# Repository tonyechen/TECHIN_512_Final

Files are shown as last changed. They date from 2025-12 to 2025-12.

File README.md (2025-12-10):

# Don't Let Scrappy Die! 🤖

A 90s-style handheld electronic game where you control a rebellious robot car named Scrappy who's determined to drive off the table. Your mission: keep Scrappy alive by countering his chaotic movements before time runs out!

## 🎮 How to Play

### Setup
1. Place Scrappy on the flat operating platform (3D printed table)
2. Turn on both the **Controller** and **Scrappy** (the robot car)
3. Wait for the NeoPixel on the controller to turn **green**
4. The OLED screen will display the connection status
5. Once connected, the main menu appears - Bluetooth connection established!

### Game Start
1. Use the **rotary encoder** to select difficulty (Easy, Medium, Hard)
2. Press the **right button** to begin the game
3. Keep Scrappy from driving off the table!

### Controls

| Button | Action | Description |
|---|---|---|
| **UP** | Forward | Prompt Scrappy to move forward |
| **DOWN** | Backward | Prompt Scrappy to move backward |
| **LEFT** | Turn Left | Prompt Scrappy to turn left |
| **RIGHT** | Turn Right | Prompt Scrappy to turn right |
| **SHAKE** (Accelerometer) | Manual Mode | Take full control for 5 seconds |

### Movement
- Scrappy will briefly in direction entered

### Manual Mode (Shake to Activate)
- **Duration:** 5 seconds of full control
- **Warning:** Scrappy will NOT automatically stop during manual mode
- **Strategy:** Use wisely! Once you input a command, Scrappy follows it continuously until you send a new command

### Game Progression
- **10 Levels Total**
- **Level 1:** 10 seconds
- **Each Additional Level:** +2 seconds (Level 10 = 28 seconds)
- Successfully keep Scrappy alive for the time limit to advance

### Difficulty Settings

| Difficulty | Behavior |
|---|---|
| **EASY** | Slow, predictable movements |
| **MEDIUM** | Moderate speed, unpredictable |
| **HARD** | Fast, chaotic, sudden changes |

Higher difficulty = more irrational behavior and sudden movements!

### Win/Lose Conditions
- **GAME OVER:** Scrappy drives off the table (detected by ADXL345 accelerometer)
- **WIN:** Complete all 10 levels without Scrappy falling
- Shake the controller to restart after Game Over (no power cycling needed!)

---

## 🔧 Components Used

### Controller (Handheld Device)
- **XIAO ESP32C3** - Main microcontroller with Bluetooth
- **SSD1306 OLED (128x64)** - Display for menus, levels, and status
- **Rotary Encoder** - Difficulty selection and menu navigation
- **ADXL345 Accelerometer** - Shake detection for manual mode activation
- **4x Tactile Buttons** - Directional controls (UP, DOWN, LEFT, RIGHT)
- **NeoPixel LEDs** - Status indicators (connection, game state, battery)
- **3.7V LiPo Battery** - Portable power supply
- **On/Off Switch** - Power control

### Scrappy (Robot Car)
- **Adafruit QT Py ESP32-S3** - Robot microcontroller with Bluetooth
- **L298N Motor Driver** - Dual H-bridge for motor control
- **2x DC Motors** - Drive system for movement
- **ADXL345 Accelerometer** - Impact/fall detection (death sensor)
- **9V Alkaline Battery** - Robot power supply
- **On/Off Switch** - Robot power control

## 💾 Software Requirements

### CircuitPython Version
- **CircuitPython 10+** (Both controller and Scrappy)

### Controller Libraries
```
lib/
├── adafruit_displayio_ssd1306    # OLED display driver
├── adafruit_display_text         # OLED display text
├── adafruit_ble/                 # Bluetooth Low Energy
├── adafruit_adxl34x.mpy          # ADXL345 accelerometer
├── adafruit_bus_device/          # I2C/SPI support
├── neopixel.mpy                  # NeoPixel LED control
└── rainbow.mpy
```

### Scrappy Libraries
```
lib/
├── adafruit_ble/                 # Bluetooth Low Energy
├── adafruit_adxl34x.mpy          # ADXL345 accelerometer
└── adafruit_bus_device/          # I2C support
```

## 🎯 Implementation Details

### Bluetooth Communication (BLE UART)
- **Protocol:** Nordic UART Service over Bluetooth Low Energy
- **Range:** ~10 meters
- **Messages:**
  - `LEVEL:X:DIFFICULTY` - Start game at level X with difficulty
  - `UP`, `DOWN`, `LEFT`, `RIGHT` - Movement commands
  - `MANUAL` - Activate 5-second manual mode
  - `STOP` - Stop Scrappy between levels and  after Game Over
- **Responses:**
  - `CONNECTED` - Initial connection established
  - `ACK` - Command received successfully
  - `DEAD` - Scrappy has fallen (Game Over)

### Accelerometer Calibration & Filtering
#### Controller (Shake Detection)
- **Calibration:** Zero-offset calibration on startup (50 samples)
- **Filtering:** z axis magnitude detection
- **Threshold:** Configurable shake sensitivity
- **Purpose:** Detect shake gesture for manual mode

#### Scrappy Robot (Fall Detection)
- **Calibration:** Zero-offset calibration on startup
- **Detection Method:** Z-axis monitoring for sudden drops
- **Threshold:** Adjustable threshold for fall detection sensitivity
- **Purpose:** Detect when Scrappy falls off the table

### Movement System
- **Random Behavior:** Algorithm generates random directions, speeds, and durations
- **Speed Ranges:**
  - Easy: 55-60% motor power
  - Medium: 60-65% motor power
  - Hard: 65-70% motor power
- **Counter-Steering:** Override Scrappy Auto Movements

### NeoPixel Indicators
| Color | Status |
|---|---|
| **Red** | Not connected |
| **Green** | Connected to Scrappy |

### Display States
1. **Splash Screen** - Game title and version
2. **Connection Screen** - Shows "BLE Client" status
3. **Main Menu** - Difficulty selection
4. **Level Screen** - Shows current level, difficulty, last command sent, and response status from Scrappy
5. **Game Over Screen** - "Scrappy Died!" with restart option
6. **Victory Screen** - "You Win!" with celebration and restart option

---

## 📦 Enclosure Design

### Controller Enclosure
**Design Philosophy:** Sci-fi inspired components with functional layout

**Layout:**
- **Top Surface:** OLED screen and control buttons
- **Side Mounted:** Rotary encoder for easy thumb access
- **Bottom Front:** On/Off switch
- **Bottom Access:** USB-C charging port slot

### Scrappy Robot Enclosure
**Design Philosophy:** Inspired by Perry the Platypus. Hat serves as the opening for the enclosure

**Layout:**
- **Bottom Back:** On/Off switch
- **Side Mounted**: Wheels for controlling movement
---

## 📁 Repository Structure

```
├── src/
│   ├── controller/
│   │   ├── code.py                 # Main controller program
│   │   ├── display.py              # OLED display management
│   │   ├── controls.py             # Button and rotary encoder handling
│   │   ├── accelerometer.py        # Shake detection
│   │   └── README.md               # Hardware and Software requirement
│   └── scrappy/
│       ├── code.py                 # Main robot program
│       ├── motor.py                # L298N motor control
│       ├── movement_patterns.py    # Random movement logic
│       ├── accelerometer.py        # Fall detection
│       └── README.md               # Hardware and Software requirement
├── Documentation/
│   ├── system_diagram.png          # Overall system architecture
│   ├── Scrappy.kicad_sch           # Circuit Diagram for Scrappy
│   └── Controller.kicad_sch        # Circuit Diagram for Controller
└── README.md                       # This file
```

---

## 🚀 Getting Started

### Software Installation
1. Install CircuitPython 10.0+ on both ESP32 boards
2. Copy all files from `src/controller/` to the controller's CIRCUITPY drive
3. Copy all files from `src/scrappy/` to Scrappy's CIRCUITPY drive
4. Ensure all required libraries are present in `lib/` for each microcontroller

### Hardware Assembly
1. Follow circuit diagrams in `Documentation/` folder
2. Connect components according to pin configuration above
3. Secure batteries with proper polarity
4. Test all connections before enclosing
5. Install firmware and test functionality
6. Assemble into enclosures

---

## 🎓 Educational Value

This project demonstrates:
- **Wireless Communication:** BLE UART protocol implementation
- **Sensor Fusion:** Accelerometer calibration and filtering
- **State Machine Design:** Game states and transitions
- **Real-Time Control:** Motor PWM control and response timing
- **User Interface:** OLED graphics and menu systems
- **Embedded Systems:** Power management, resource constraints
- **Mechanical Design:** Enclosure design and assembly
- **Version Control:** Git/GitHub workflow

---

## 🏆 Credits

**Project Type:** Final Project for Embedded Systems Course  
**Inspired By:** 90s handheld games (Bop It, Brain Warp)  
**Platform:** CircuitPython on ESP32  
**License:** MIT

**Special Thanks:**
- TECHIN 512 Teaching team for guidance and component provision
- Maker Space for tools and materials
- Adafruit for excellent CircuitPython libraries

---

## 📝 License

MIT License - Feel free to modify and share!

---

**Remember:** Scrappy wants to die. Don't let him. Good luck! 🎮🤖

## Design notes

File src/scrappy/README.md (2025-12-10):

## Library Needed:
- adafruit_ble
- adafruit_adxl34x.mpy
- adafruit_bus_device

## Hardward requirement:
- 1 QT Py ESP32-S3
- 1 Switch
- 1 9V Alkaline battery
- 1 Accelerometer (ADXL 345)
- 2 DC Motors
- 1 L298N Motor Driver

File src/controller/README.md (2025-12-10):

Library Needed:
- adafruit_ble
- adafruit_bus_device
- adafruit_display_text
- adafruit_adxl34x.mpy
- adafruit_displayio_ssd1306
- neopixel.mpy
- rainbow.mpy

Hardward requirement:
- 1 Xiao ESP32C3
- 1 Neopixel
- 1 SSD1306 OLED screen
- 4 Push Buttons
- 1 rotary encoder
- 1 switch
- 1 3.7V LiPo Battery
- 1 Accelerometer (ADXL 345)

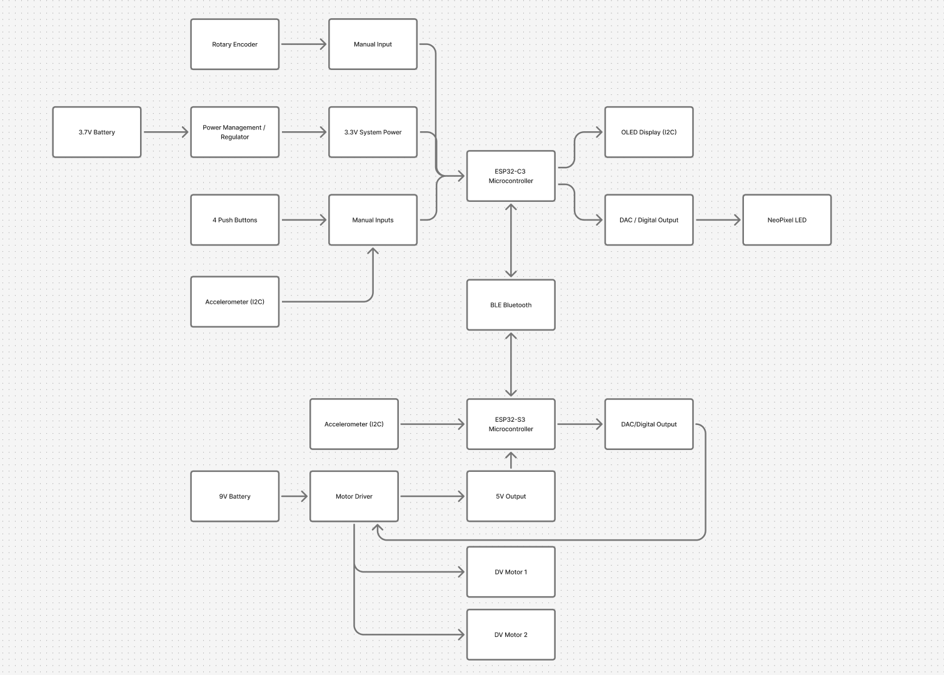
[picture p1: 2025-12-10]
Documentation/system_diagram.png

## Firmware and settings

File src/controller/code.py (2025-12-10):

import board
import time
import busio
import displayio
import i2cdisplaybus
import adafruit_displayio_ssd1306
from adafruit_ble import BLERadio
from adafruit_ble.advertising.standard import ProvideServicesAdvertisement
from adafruit_ble.services.nordic import UARTService
from buttons import Buttons
from accelerometer import Accelerometer
from display import DisplayManager
from rotary_encoder import RotaryEncoder
from neopixel_status import NeoPixelStatus

# Release any existing displays
displayio.release_displays()

# Setup I2C for OLED
i2c = busio.I2C(board.SCL, board.SDA)
display_bus = i2cdisplaybus.I2CDisplayBus(i2c, device_address=0x3C)
display = adafruit_displayio_ssd1306.SSD1306(display_bus, width=128, height=64)

# Initialize display manager
display_mgr = DisplayManager(display)

# Initialize accelerometer
accelerometer = Accelerometer(i2c=i2c, shake_threshold=15.0, cooldown_time=0.5)
print("Calibrating accelerometer...")
accelerometer.calibrate(20)
print("Accelerometer ready!")

# Initialize buttons
buttons = Buttons()

# Initialize rotary encoder
encoder = RotaryEncoder(board.D10, board.D9, pulses_per_detent=3)

# Initialize NeoPixel status LED
neopixel_status = NeoPixelStatus(pin=board.D8)

# Initialize BLE
ble = BLERadio()

print("BLE Client Ready")

connection = None
LEVEL_LENGTH = 10
LEVEL1_LENGTH = 10
ADD_TIME = 2
MAX_LEVEL = 10  # Win after completing level 10

while True:
    # ===== CONNECTION PHASE =====
    neopixel_status.show_disconnected()  # Show red while not connected
    display_mgr.show_connection_screen()
    display_mgr.update_connection_status("Scanning...", "")
    print("Searching for BLE Server...")
    
    connection = None
    
    # Scan for devices
    for advertisement in ble.start_scan(ProvideServicesAdvertisement, timeout=10):
        if UARTService in advertisement.services:
            print("Found server! Connecting...")
            display_mgr.update_connection_status("Connecting...", "")
            try:
                connection = ble.connect(advertisement)
                print(f"Connection established: {connection.connected}")
                break
            except Exception as e:
                print(f"Connection failed: {e}")
                connection = None
    
    ble.stop_scan()
    
    if connection and connection.connected:
        print("Connected!")
        neopixel_status.show_connected()  # Show green when connected
        display_mgr.update_connection_status("Connected!", "Initializing...")
        time.sleep(1)
        uart = connection[UARTService]
        
        # ===== MAIN GAME SESSION LOOP =====
        session_active = True
        
        while connection.connected and session_active:
            
            # ===== MENU PHASE =====
            display_mgr.show_menu_screen()
            menu_active = True
            encoder.reset(to_detent=0)
            
            while connection.connected and menu_active:
                # Update encoder and check for rotation
                if encoder.update():
                    delta = encoder.get_delta()
                    
                    if delta > 0:
                        for _ in range(abs(delta)):
                            display_mgr.menu_move_down()
                        print(f"Selected: {display_mgr.get_difficulty_name()}")
                
                # Check for RIGHT button to confirm selection
                button_pressed = buttons.get_pressed_button()
                
                if button_pressed == "RIGHT":
                    selected_difficulty = display_mgr.get_difficulty_name()
                    print(f"Starting game on {selected_difficulty} mode")
                    menu_active = False
                    while buttons.any_button_pressed():
                        time.sleep(0.01)
                    time.sleep(0.1)
                
                time.sleep(0.001)
            
            if not connection.connected:
                break
            
            # ===== GAME PHASE =====
            game_level = 1
            display_mgr.show_game_screen()
            display_mgr.update_level(game_level)
            print(f"Game started! Difficulty: {display_mgr.get_difficulty_name()}")
            
            # Send difficulty to server
            difficulty_msg = f"LEVEL:{str(game_level)}:{display_mgr.get_difficulty_name()}\n"
            uart.write(difficulty_msg.encode('utf-8'))
            print(f"Sent: {difficulty_msg.strip()}")
            
            game_start = time.monotonic()
            print(f"Level {game_level} started at: {game_start}")
            
            # Main game loop
            game_running = True
            
            while connection.connected and game_running:
                
                # ===== PLAYING =====
                if display_mgr.is_game_screen():
                    time_left = LEVEL_LENGTH - (time.monotonic() - game_start)
                    
                    # Level complete
                    if time_left <= 0:
                        # Check if player won (completed level 10)
                        if game_level >= MAX_LEVEL:
                            display_mgr.show_game_win_screen()
                            message = "STOP\n"
                            uart.write(message.encode('utf-8'))
                            print("Game completed! Player wins!")
                            continue
                        
                        # Otherwise, go to next level
                        game_level += 1
                        display_mgr.show_transition_screen(game_level)
                        message = "STOP\n"
                        uart.write(message.encode('utf-8'))
                        print(f"Level {game_level - 1} complete!")
                        continue  # Skip to next iteration to handle transition
                    
                    display_mgr.update_timer(int(time_left))
                    
                    # Check for incoming messages from server (e.g., DEAD)
                    if uart.in_waiting:
                        data = uart.read(uart.in_waiting)
                        if data:
                            received = data.decode('utf-8').strip()
                            print(f"Received (unsolicited): {received}")
                            
                            if "DEAD" in received:
                                reason = "Scrappy Died!"
                                display_mgr.show_game_over_screen(reason)
                                print(f"Game Over: {reason}")
                                continue
                    
                    # Check for player input
                    message = None
                    shake = accelerometer.detect_z_shake(time.monotonic())
                    
                    if shake:
                        message = "MANUAL\n"
                        display_mgr.update_command("Sent: MANUAL")
                    else:
                        button_pressed = buttons.get_pressed_button()
                        if button_pressed:
                            message = f"{button_pressed}\n"
                            display_mgr.update_command(f"Sent: {button_pressed}")
                    
                    if message:
                        uart.write(message.encode('utf-8'))
                        print(f"Sent: {message.strip()}")
                        
                        display_mgr.update_response("Waiting...")
                        response_received = False
                        response_timeout = time.monotonic() + 2  # 2 second timeout
                        
                        while connection.connected and not response_received and time.monotonic() < response_timeout:
                            if uart.in_waiting:
                                data = uart.read(uart.in_waiting)
                                if data:
                                    received = data.decode('utf-8').strip()
                                    print(f"Received: {received}")
                                    
                                    if "DEAD" in received:
                                        reason = "Scrappy Died!"
                                        display_mgr.show_game_over_screen(reason)
                                        LEVEL_LENGTH = LEVEL1_LENGTH
                                        print(f"Game Over: {reason}")
                                        # Don't set game_running = False here either
                                    else:
                                        display_mgr.update_response("ACK OK!")
                                    
                                    response_received = True
                        
                        if not response_received:
                            display_mgr.update_response("Timeout")
                            print("Warning: No response from server")
                        
                        time.sleep(0.1)
                        display_mgr.update_response("")

                
                # ===== LEVEL TRANSITION =====
                elif display_mgr.is_transition_screen():
                    time.sleep(2)
                    
                    LEVEL_LENGTH += ADD_TIME
                    # Clear pending data
                    if uart.in_waiting:
                        uart.read(uart.in_waiting)
                    
                    # Send new level info
                    message = f"LEVEL:{str(game_level)}:{display_mgr.get_difficulty_name()}\n"
                    uart.write(message.encode('utf-8'))
                    print(f"Sent: {message.strip()}")
                    
                    # Wait for ACK
                    response_received = False
                    timeout = time.monotonic() + 5
                    
                    while connection.connected and not response_received and time.monotonic() < timeout:
                        if uart.in_waiting:
                            data = uart.read(uart.in_waiting)
                            if data:
                                received = data.decode('utf-8').strip()
                                print(f"Level ACK: {received}")
                                response_received = True
                    
                    # Return to game and reset timer
                    display_mgr.show_game_screen()
                    display_mgr.update_level(game_level)
                    game_start = time.monotonic()
                    print(f"Level {game_level} started at: {game_start}")
                
                # ===== GAME OVER =====
                elif display_mgr.is_game_over_screen():
                    print("Waiting for shake to restart...")
                    LEVEL_LENGTH = LEVEL1_LENGTH
                    if accelerometer.detect_z_shake(time.monotonic()):
                        print("Restarting game...")
                        game_running = False  # Exit game loop, return to menu
                
                # ===== GAME WIN =====
                elif display_mgr.is_game_win_screen():
                    print("Waiting for shake to return to menu...")
                    LEVEL_LENGTH = LEVEL1_LENGTH
                    if accelerometer.detect_z_shake(time.monotonic()):
                        print("Returning to menu...")
                        game_running = False  # Exit game loop, return to menu
                
                time.sleep(0.01)
            
            # If connection lost during game, exit session
            if not connection.connected:
                session_active = False
        
        print("Disconnected from server")
        neopixel_status.show_disconnected()  # Show red when disconnected
        display_mgr.update_connection_status("Disconnected", "")
        time.sleep(2)
    else:
        print("Server not found or connection failed")
        neopixel_status.show_disconnected()  # Show red when connection failed
        display_mgr.update_connection_status("Not found", "Retrying...")
        time.sleep(2)

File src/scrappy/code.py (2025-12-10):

import time
from adafruit_ble import BLERadio
from adafruit_ble.advertising.standard import ProvideServicesAdvertisement
from adafruit_ble.services.nordic import UARTService
import motor
from movement_patterns import MovementController
from accelerometer import AccelerometerMonitor

ble = BLERadio()
uart = UARTService()
advertisement = ProvideServicesAdvertisement(uart)

# Initialize controllers
movement = MovementController()
accel = AccelerometerMonitor()

# Configuration
MANUAL_MOVE_DURATION = 0.2  # seconds for individual moves
MANUAL_MODE_DURATION = 5.0  # seconds for full manual control mode
BASE_SPEED = 60

def send_response(message):
    """Send response over BLE"""
    try:
        uart.write(f"{message}\n".encode('utf-8'))
        print(f"Sent: {message}")
    except:
        pass

def handle_connection():
    """Handle BLE connection process"""
    print("Waiting for connection...")
    ble.start_advertising(advertisement)
    
    while not ble.connected:
        time.sleep(0.1)
    
    print("Connected!")
    ble.stop_advertising()

accel.calibrate()

while True:
    # Wait for connection
    handle_connection()
    
    # State variables
    state = "WAITING"  # WAITING, AUTO, MANUAL, DEAD
    manual_mode_end_time = 0
    user_move_end_time = 0
    
    movement.reset()
    accel.reset()
    
    # Connection loop
    try:
        while ble.connected:
            current_time = time.monotonic()
            
            # Check for death (only when alive)
            if state != "DEAD" and state != "WAITING":
                if accel.check_impact():
                    motor.stop()
                    state = "DEAD"
                    send_response("DEAD")
                    print("Robot died!")
            
            message = None
            # Handle incoming messages
            if uart.in_waiting:
                data = uart.read(uart.in_waiting)
                message = data.decode('utf-8').strip()
                print(f"Received: {message}")
                
                # LEVEL command - starts/restarts the game
                if message.startswith("LEVEL:"):
                    try:
                        parts = message.split(":")
                        level = int(parts[1])
                        difficulty = parts[2].upper()
                        
                        if difficulty in ["EASY", "MEDIUM", "HARD"]:
                            accel.reset()
                            movement.set_level(level, difficulty)
                            state = "AUTO"
                            user_move_end_time = 0  # Reset user move timer
                            send_response("ACK")
                            print(f"Started level {level} - {difficulty}")
                        else:
                            send_response("ACK")
                    except:
                        send_response("ACK")
                
                # MANUAL mode - 5 seconds of full control
                elif message == "MANUAL":
                    if state == "AUTO":
                        state = "MANUAL"
                        manual_mode_end_time = current_time + MANUAL_MODE_DURATION
                        motor.stop()
                        send_response("ACK")
                        print("Manual mode: 5 seconds of full control")
                
                # Movement commands
                elif message == "UP":
                    if state == "MANUAL":
                        # Continuous movement in manual mode
                        motor.forward(BASE_SPEED)
                    elif state == "AUTO":
                        # Execute user move and block auto for duration
                        motor.stop()  # Stop any current movement first
                        motor.forward(BASE_SPEED)
                        user_move_end_time = current_time + MANUAL_MOVE_DURATION
                    send_response("ACK")
                
                elif message == "DOWN":
                    if state == "MANUAL":
                        motor.backward(BASE_SPEED)
                    elif state == "AUTO":
                        motor.stop()
                        motor.backward(BASE_SPEED)
                        user_move_end_time = current_time + MANUAL_MOVE_DURATION
                    send_response("ACK")
                
                elif message == "LEFT":
                    if state == "MANUAL":
                        motor.left(BASE_SPEED)
                    elif state == "AUTO":
                        motor.stop()
                        motor.left(BASE_SPEED)
                        user_move_end_time = current_time + MANUAL_MOVE_DURATION
                    send_response("ACK")
                
                elif message == "RIGHT":
                    if state == "MANUAL":
                        motor.right(BASE_SPEED)
                    elif state == "AUTO":
                        motor.stop()
                        motor.right(BASE_SPEED)
                        user_move_end_time = current_time + MANUAL_MOVE_DURATION
                    send_response("ACK")
                
                elif message == "STOP":
                    motor.stop()
                    user_move_end_time = 0
                    state = "WAITING"
                    send_response("ACK")
                
                else:
                    send_response("ACK")
            
            # Update movement states
            if state == "AUTO":
                # Only run auto mode if user move timer has expired
                if current_time >= user_move_end_time: # add one here for a short delay before the robot makes another random move
                    # Execute auto random movements
                    movement.update_auto_mode()
                # else: user command is still executing, don't interfere
            
            elif state == "MANUAL":
                # Check if manual mode expired
                if current_time >= manual_mode_end_time:
                    state = "AUTO"
                    motor.stop()
                    movement.reset()
                    user_move_end_time = 0  # Reset timer
                    print("Manual mode ended, back to auto")
            
            elif state == "DEAD":
                motor.stop()
            
    
    except Exception as e:
        print(f"Error: {e}")
    
    finally:
        print("Disconnected!")
        motor.stop()
        ble.stop_advertising()
        time.sleep(0.5)

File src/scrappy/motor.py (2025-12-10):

import board
import pwmio
import digitalio
import time

# QT Py ESP32-S3 pin mapping
# You'll need to choose actual pins from: A0, A1, A2, A3, SCK, MISO, MOSI, TX, RX, SCL, SDA
# Here's a suggested mapping using available GPIO pins:

# Motor A pins
ENA = pwmio.PWMOut(board.SCK, frequency=5000)   # Was D8
IN1 = digitalio.DigitalInOut(board.MISO)         # Was D9
IN2 = digitalio.DigitalInOut(board.MOSI)         # Was D10

# Motor B pins
IN3 = digitalio.DigitalInOut(board.A3)         # Was D3
IN4 = digitalio.DigitalInOut(board.A2)        # Was D2
ENB = pwmio.PWMOut(board.A1, frequency=5000) # Was D1

# Configure direction pins as outputs
IN1.direction = digitalio.Direction.OUTPUT
IN2.direction = digitalio.Direction.OUTPUT
IN3.direction = digitalio.Direction.OUTPUT
IN4.direction = digitalio.Direction.OUTPUT

# Initialize motors to stopped state
IN1.value = False
IN2.value = False
IN3.value = False
IN4.value = False

def set_speed(pwm_pin, speed):
    """Set motor speed (0-100%)"""
    time.sleep(0.02)
    duty = int((80 / 100) * 65535)
    pwm_pin.duty_cycle = max(0, min(65535, duty))
    time.sleep(0.01)
    duty = int((speed / 100) * 65535)
    pwm_pin.duty_cycle = max(0, min(65535, duty))

def forward(speed=10):
    """Move both motors forward"""
    # Motor A forward
    IN1.value = True
    IN2.value = False
    set_speed(ENA, speed)
    
    # Motor B forward
    IN3.value = True
    IN4.value = False
    set_speed(ENB, speed)
    print("Moving Forward")

def backward(speed=10):
    """Move both motors backward"""
    # Motor A backward
    IN1.value = False
    IN2.value = True
    set_speed(ENA, speed)
    
    # Motor B backward
    IN3.value = False
    IN4.value = True
    set_speed(ENB, speed)
    print("Moving Backward")

def right(speed=10):
    """Turn left (Motor A backward, Motor B forward)"""
    # Motor A backward
    IN1.value = False
    IN2.value = True
    set_speed(ENA, speed)
    
    # Motor B forward
    IN3.value = True
    IN4.value = False
    set_speed(ENB, speed)
    print("Turning RIGHT")

def left(speed=10):
    """Turn right (Motor A forward, Motor B backward)"""
    # Motor A forward
    IN1.value = True
    IN2.value = False
    set_speed(ENA, speed)
    
    # Motor B backward
    IN3.value = False
    IN4.value = True
    set_speed(ENB, speed)
    print("Turning LEFT")

def stop():
    """Stop both motors"""
    IN1.value = False
    IN2.value = False
    set_speed(ENA, 0)
    
    IN3.value = False
    IN4.value = False
    set_speed(ENB, 0)

def motor_a(speed, forward=True):
    """Control Motor A individually (speed 0-100%)"""
    if forward:
        IN1.value = True
        IN2.value = False
    else:
        IN1.value = False
        IN2.value = True
    set_speed(ENA, abs(speed))

def motor_b(speed, forward=True):
    """Control Motor B individually (speed 0-100%)"""
    if forward:
        IN3.value = True
        IN4.value = False
    else:
        IN3.value = False
        IN4.value = True
    set_speed(ENB, abs(speed))

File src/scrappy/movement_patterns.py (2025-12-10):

import time
import random
import motor

class MovementController:
    """Class to handle random movement patterns for the robot"""
    
    # Difficulty settings
    DIFFICULTY_SETTINGS = {
        "EASY": {
            "speed_range": (55, 60),
            "duration_range": (0.2, 0.5),
            "pause_range": (1.5, 2.0)
        },
        "MEDIUM": {
            "speed_range": (60, 65),
            "duration_range": (0.4, 0.6),
            "pause_range": (0.0, 1.5)
        },
        "HARD": {
            "speed_range": (70, 75),
            "duration_range": (0.3, 1.0),
            "pause_range": (0.4, 0.5)
        }
    }
    
    def __init__(self):
        """Initialize the movement controller"""
        self.current_level = 0
        self.current_difficulty = "EASY"
        
        # Auto mode state tracking
        self.move_end_time = 0
        self.is_pausing = False
        
        print("MovementController initialized")
    
    def reset(self):
        """Reset the movement controller"""
        motor.stop()
        self.move_end_time = 0
        self.is_pausing = False
        print("MovementController reset")
    
    def set_level(self, level, difficulty):
        """Set game level and difficulty"""
        self.current_level = level
        self.current_difficulty = difficulty.upper()
        self.reset()
        print(f"Level set to {level} - {self.current_difficulty}")
    
    def get_random_move(self):
        """Generate a random movement command"""
        settings = self.DIFFICULTY_SETTINGS[self.current_difficulty]
        
        return {
            "direction": random.choice(["forward", "backward", "left", "right"]),
            "speed": random.randint(*settings["speed_range"]),
            "duration": random.uniform(*settings["duration_range"]),
            "pause": random.uniform(*settings["pause_range"])
        }
    
    def update_auto_mode(self):
        """Update auto mode movement (non-blocking)"""
        current_time = time.monotonic()
        
        # Check if current action finished
        if current_time < self.move_end_time:
            return 
        
        if self.is_pausing:
            # Pause finished, start new move
            move = self.get_random_move()
            
            # Execute motor command
            if move["direction"] == "forward":
                motor.forward(move["speed"])
            elif move["direction"] == "backward":
                motor.backward(move["speed"])
            elif move["direction"] == "left":
                motor.left(move["speed"])
            elif move["direction"] == "right":
                motor.right(move["speed"])
            
            self.move_end_time = current_time + move["duration"]
            self.is_pausing = False
            print(f"Auto: {move['direction']} @ {move['speed']}% for {move['duration']:.1f}s")
        
        else:
            # Move finished, start pause
            motor.stop()
            move = self.get_random_move()
            self.move_end_time = current_time + move["pause"]
            self.is_pausing = True
            print(f"Pausing for {move['pause']:.1f}s")

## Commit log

2025-12-03 added schematics
    [final_schematic.kicad_sch]
2025-12-10 code added
    [Controller.kicad_sch]
2025-12-10 added circuit diagrams
    [Srappy.kicad_sch]
